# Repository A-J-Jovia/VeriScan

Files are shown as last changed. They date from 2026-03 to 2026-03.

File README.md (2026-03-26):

# VeriScan: Deep-Tech Multispectral Pill Authentication

**Domain:** IoT, Edge AI, Optical Physics, Healthcare Security  

## 📖 Executive Summary

VeriScan is a non-destructive hardware and software system designed to detect counterfeit pharmaceutical pills in under 5 seconds. By utilizing a **45/0 optical geometry** and an **18-channel multispectral optical sensor (AS7343)**, the system captures the unique chemical reflectance fingerprint of a pill.

Unlike basic colorimeters, VeriScan utilizes **Differential Optical Reading** (subtracting thermal/ambient dark current at the Edge) and **Row-wise L1 Normalization** (in the Cloud) to eliminate spatial placement variance and isolate the pure chemical signature for Machine Learning classification.

---

## 🏗️ System Architecture

VeriScan is a distributed IoT system divided into three distinct operational domains:

### 1. The Edge (Hardware & Firmware)

* **Microcontroller:** ESP32 DevKit V1 (C++)
* **Sensor:** Adafruit AS7343 (I2C)
* **Chassis:** Custom 5mm matte black PVC sunboard enclosure designed for absolute light isolation and strict 45-degree LED illumination.
* **Firmware Protocol:** Calculates differential (Light - Dark) readings and transmits a packed 36-byte binary struct (Little-Endian) over BLE to avoid MTU bottlenecks and heap fragmentation.

### 2. The Gateway (Mobile App)

* **Framework:** Flutter / Dart
* **Function:** Connects via BLE (MTU negotiated > 128 bytes), unpacks the 36-byte binary payload into an 18-channel integer array, and acts as the HTTP bridge to the inference engine.

### 3. The Brain (Backend & AI)

* **Server:** Python / FastAPI
* **Engine:** Scikit-Learn `Pipeline` (`Normalizer(norm='l1')` -> `RandomForestClassifier`)
* **Pipeline Logic:** Drops saturated hardware channels (CH6, CH12, CH18), normalizes the remaining 15-channel spectrum to extract the chemical ratio, and returns a strict "Real" or "Fake" verdict.

---

## 📂 Repository Structure

```text
VeriScan/
├── firmware/                 # C++ Edge Code (PlatformIO / Arduino IDE)
│   └── src/main.cpp          # BLE & AS7343 Differential Reading Logic
├── backend/                  # Python API and ML Pipeline
│   ├── api.py                # FastAPI Inference Server
│   ├── model.py              # ML Training Script (Run to generate .pkl)
│   ├── requirements.txt      # Python dependencies
│   └── veriscan_pipeline.pkl # Compiled Scikit-Learn Pipeline
├── mobile_app/               # Flutter Gateway (BLE to HTTP bridge)
│   └── lib/                  # Dart source code
└── README.md
```

## 🚀 Quick Start & Reproduction

### Phase 1: Backend Setup

1. Navigate to the backend directory: `cd backend/`

2. Install dependencies: `pip install -r requirements.txt`

3. Generate the ML Pipeline: `python model.py` (Requires a valid `scans.csv` dataset in the folder)

4. Boot the Inference API: `uvicorn api:app --host 0.0.0.0 --port 8000`

5. Verify API is alive at: <http://localhost:8000/docs>

### Phase 2: Hardware Flashing

 1. Open `firmware/src/main.cpp` in your IDE.

 2. Ensure you have the `Adafruit_AS7341` (or AS7343 compatible) library installed.

 3. Flash to the ESP32.

 4. *Note: Ensure your IR LEDs are properly resisted to prevent CH18 saturation before gathering production data.*

 ### Phase 3: Mobile Gateway

 1. Navigate to `mobile_app/` and run flutter pub get.

 2. Update the `api_service.dart` file with the local IP address or Cloud URL of your FastAPI backend.

 3. Compile and run on a physical mobile device (BLE does not work on emulators): `flutter run` 

## ⚠️ Known Hardware Constraints (Pending V3)

* Saturated NIR Band: Depending on LED drive current, the Near-IR band (CH18) may hit ADC maximums (59998). Current backend logic strictly drops this channel to maintain ML integrity until LED dimming/resistor tuning is applied.

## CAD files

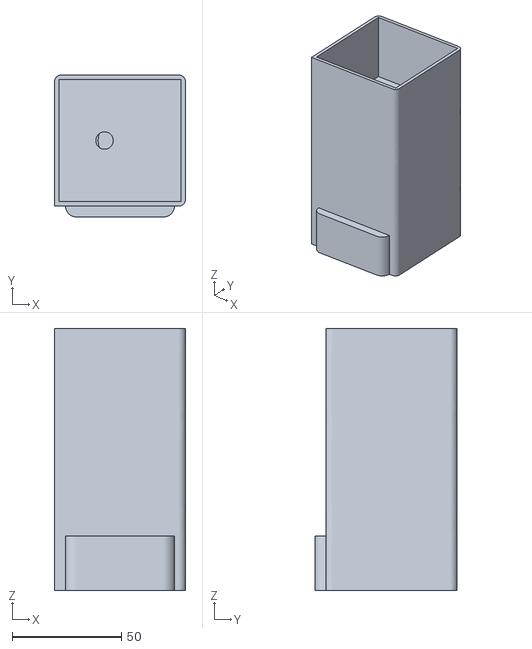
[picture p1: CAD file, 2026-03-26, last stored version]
Hardware/3D designing/VeriSacn V1.stl
60.0 x 65.0 x 120.0

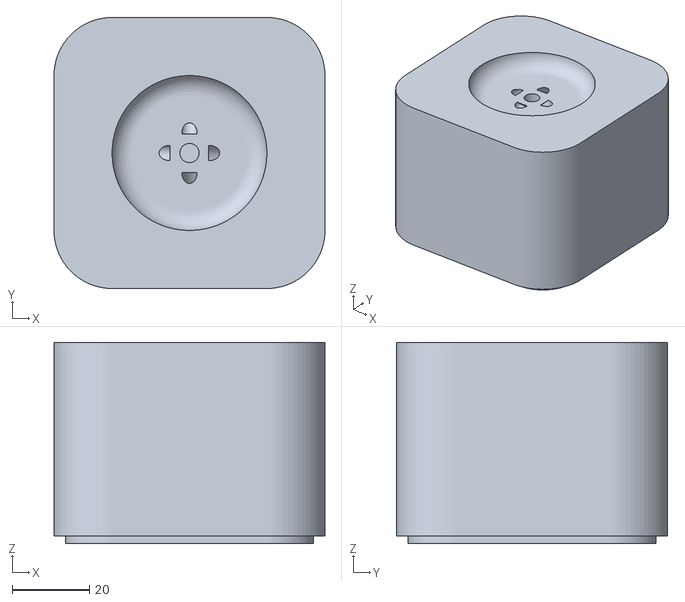
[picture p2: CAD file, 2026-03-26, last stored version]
Hardware/3D designing/VeriScan V2 - Pod.stl
70.0 x 70.0 x 52.0

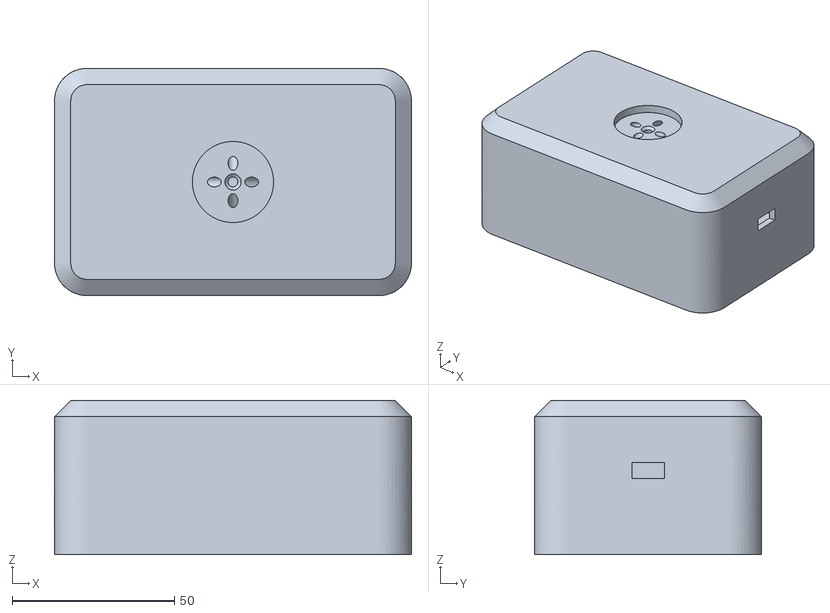
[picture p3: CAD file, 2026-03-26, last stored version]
Hardware/3D designing/VeriScan V3.stl
110.0 x 70.0 x 47.5

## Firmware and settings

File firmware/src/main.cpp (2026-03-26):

#include "Wire.h"
#include "Adafruit_AS7343.h"
#include <BLEDevice.h>
#include <BLEServer.h>
#include <BLEUtils.h>
#include <BLE2902.h>

// --- BLE UUIDS ---
#define SERVICE_UUID        "4fafc201-1fb5-459e-8fcc-c5c9c331914b"
#define CHARACTERISTIC_UUID "beb5483e-36e1-4688-b7f5-ea07361b26a8"

BLEServer* pServer = NULL;
BLECharacteristic* pCharacteristic = NULL;
bool deviceConnected = false;
bool oldDeviceConnected = false;

// --- PIN DEFINITIONS ---
#define SDA_PIN 33
#define SCL_PIN 32
#define LED_VIS_1 26  
#define LED_IR_1  27  
#define LED_VIS_2 18  
#define LED_IR_2  19  

Adafruit_AS7343 as7343 = Adafruit_AS7343();

// We pack the 18 channels into a struct. This takes exactly 36 bytes of RAM.
// No strings, no heap fragmentation.
#pragma pack(push, 1)
struct SensorPayload {
  uint16_t channels[18];
};
#pragma pack(pop)

SensorPayload payload;

// --- NON-BLOCKING TIMER ---
unsigned long lastScanTime = 0;
const unsigned long SCAN_INTERVAL = 2000; // 2 seconds

// --- BLE CONNECTION CALLBACKS ---
class MyServerCallbacks: public BLEServerCallbacks {
    void onConnect(BLEServer* pServer) {
      deviceConnected = true;
      Serial.println("PHONE CONNECTED!");
    };
    void onDisconnect(BLEServer* pServer) {
      deviceConnected = false;
      Serial.println("PHONE DISCONNECTED!");
    }
};

void setup() {
  Serial.begin(115200);
  
  pinMode(LED_VIS_1, OUTPUT); pinMode(LED_IR_1, OUTPUT);
  pinMode(LED_VIS_2, OUTPUT); pinMode(LED_IR_2, OUTPUT);
  
  // Ensure LEDs are OFF on boot
  turnOffLEDs();

  Wire.begin(SDA_PIN, SCL_PIN);
  if (!as7343.begin(0x39, &Wire)) { 
    Serial.println("FATAL: Sensor not found!");
    while (1); // Halt
  }

  as7343.setGain(AS7343_GAIN_1024X); 
  as7343.setATIME(99);               
  as7343.setASTEP(599);              

  // --- START BLE SERVER ---
  BLEDevice::init("VeriScan_BLE");
  
  // Increase MTU so our 36-byte struct fits in one packet
  BLEDevice::setMTU(128); 
  
  pServer = BLEDevice::createServer();
  pServer->setCallbacks(new MyServerCallbacks());

  BLEService *pService = pServer->createService(SERVICE_UUID);

  pCharacteristic = pService->createCharacteristic(
                      CHARACTERISTIC_UUID,
                      BLECharacteristic::PROPERTY_READ   |
                      BLECharacteristic::PROPERTY_NOTIFY
                    );

  pCharacteristic->addDescriptor(new BLE2902());
  pService->start();

  BLEAdvertising *pAdvertising = BLEDevice::getAdvertising();
  pAdvertising->addServiceUUID(SERVICE_UUID);
  pAdvertising->setScanResponse(true);
  BLEDevice::startAdvertising();

  Serial.println("\n--- BLE READY ---");
}

void loop() {
  // Handle Disconnection cleanly without blocking
  if (!deviceConnected && oldDeviceConnected) {
      delay(500); // Give the Bluetooth stack a moment to reset
      pServer->startAdvertising(); 
      Serial.println("Restarted Advertising...");
      oldDeviceConnected = deviceConnected;
  }
  
  if (deviceConnected && !oldDeviceConnected) {
      oldDeviceConnected = deviceConnected;
  }

  // Non-blocking timer for measurements
  if (deviceConnected && (millis() - lastScanTime >= SCAN_INTERVAL)) {
    lastScanTime = millis();
    performScientificScan();
  }
}

// --- HELPER FUNCTIONS ---

void turnOnLEDs() {
  digitalWrite(LED_VIS_1, HIGH); digitalWrite(LED_IR_1, HIGH);
  digitalWrite(LED_VIS_2, HIGH); digitalWrite(LED_IR_2, HIGH);
}

void turnOffLEDs() {
  digitalWrite(LED_VIS_1, LOW); digitalWrite(LED_IR_1, LOW);
  digitalWrite(LED_VIS_2, LOW); digitalWrite(LED_IR_2, LOW);
}

void performScientificScan() {
    uint16_t darkScan[18];
    uint16_t lightScan[18];

    // 1. READ DARK CURRENT (Ambient + Thermal Noise)
    // LEDs are OFF
    as7343.startMeasurement();
    while (!as7343.dataReady()) { delay(1); } // Library limitation, minor block
    as7343.readAllChannels(darkScan);

    // 2. TURN ON ILLUMINATION
    turnOnLEDs();
    delay(50); // Allow LED phosphor to stabilize

    // 3. READ SIGNAL (Pill Reflectance + Noise)
    as7343.startMeasurement();
    while (!as7343.dataReady()) { delay(1); }
    as7343.readAllChannels(lightScan);

    // 4. TURN OFF LEDs IMMEDIATELY (Prevent thermal buildup)
    turnOffLEDs();

    // 5. DIFFERENTIAL CALCULATION & PACKING
    for(int i = 0; i < 18; i++) {
      // Subtract dark noise. Prevent negative overflow if noise spiked.
      if (lightScan[i] > darkScan[i]) {
        payload.channels[i] = lightScan[i] - darkScan[i];
      } else {
        payload.channels[i] = 0; 
      }
    }

    // 6. TRANSMIT BINARY STRUCT OVER BLE
    // We send the memory address of the struct, and its exact size (36 bytes)
    pCharacteristic->setValue((uint8_t*)&payload, sizeof(payload));
    pCharacteristic->notify();
    
    Serial.println("Sent Differential Binary Data.");
}

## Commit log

2026-03-26 added 3d design and esp firmware code
    [VeriScan V1.stl, VeriScan V2 - Pod.stl, VeriScan V3.stl]
2026-03-26 Remove obsolete 3D design files from the repository
    [VeriSacn V1.stl, VeriScan V2 - Pod.stl, VeriScan V3.stl]
2026-03-26 Implement FastAPI backend with prediction endpoint and model training script
    [scans.csv]
